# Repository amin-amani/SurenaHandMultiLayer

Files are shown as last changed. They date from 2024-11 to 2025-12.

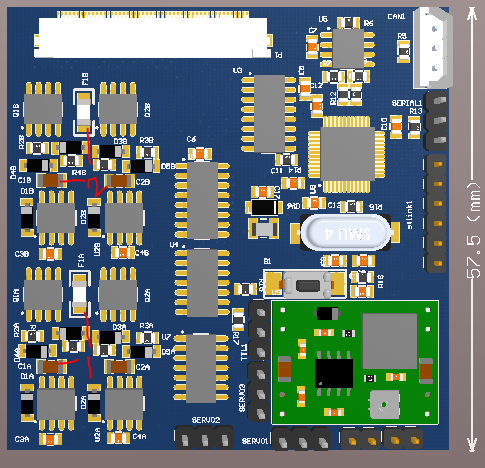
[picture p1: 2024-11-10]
Documentation/motor.PNG

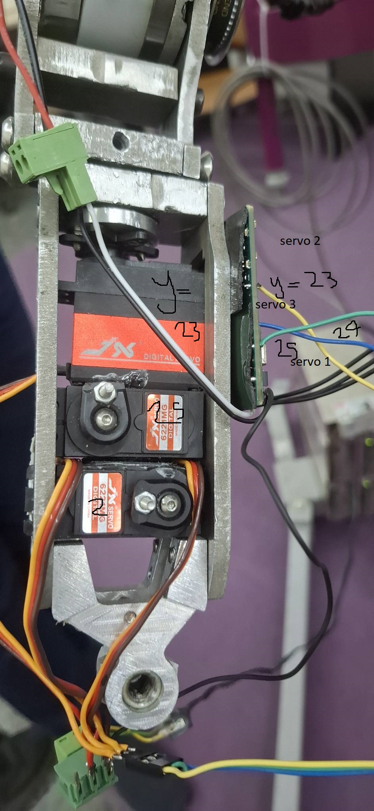
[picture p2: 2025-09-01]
Documentation/servo-connection.jpg

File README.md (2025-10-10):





# SurenaHandMultiLayer

This project provides firmware to control a robotic hand with multiple fingers. It integrates motor control, sensor feedback, and communication over CAN bus, enabling precise manipulation and customization for each finger.

## Features

6 Motor Control: Independently control each finger using dedicated motor drivers.

## Sensor Feedback:

BMP280 Sensors: Measure pressure/altitude data for feedback.

Potentiometers: Provide real-time position feedback of fingers.

CAN Bus Communication: Accepts commands via CAN for integration with other controllers or systems.

Finger Customization: Assign and configure individual PID values for each finger.

Extra Servo Output: Additional output for auxiliary mechanisms or accessories.

## Hardware Requirements

Robotic hand with 6 actuated fingers

BMP280 sensors for pressure/position measurement

Potentiometers on each finger for position feedback

Microcontroller with CAN interface

Motor drivers compatible with chosen motors

Optional servo for additional output

## Build Instructions:

use STM32CubeIDE

Flash Firmware:

st-flash write <firmware.bin> 0x8000000

## Usage

Send commands via CAN to control finger positions.

Monitor sensor feedback (BMP280 and potentiometers) for precise control.

Configure each finger using the IDE controller parameters.

Utilize the extra servo output for additional functionality.

## Contributing

Contributions are welcome! Please open an issue or submit a pull request with improvements, bug fixes, or new features.

## License

GPL

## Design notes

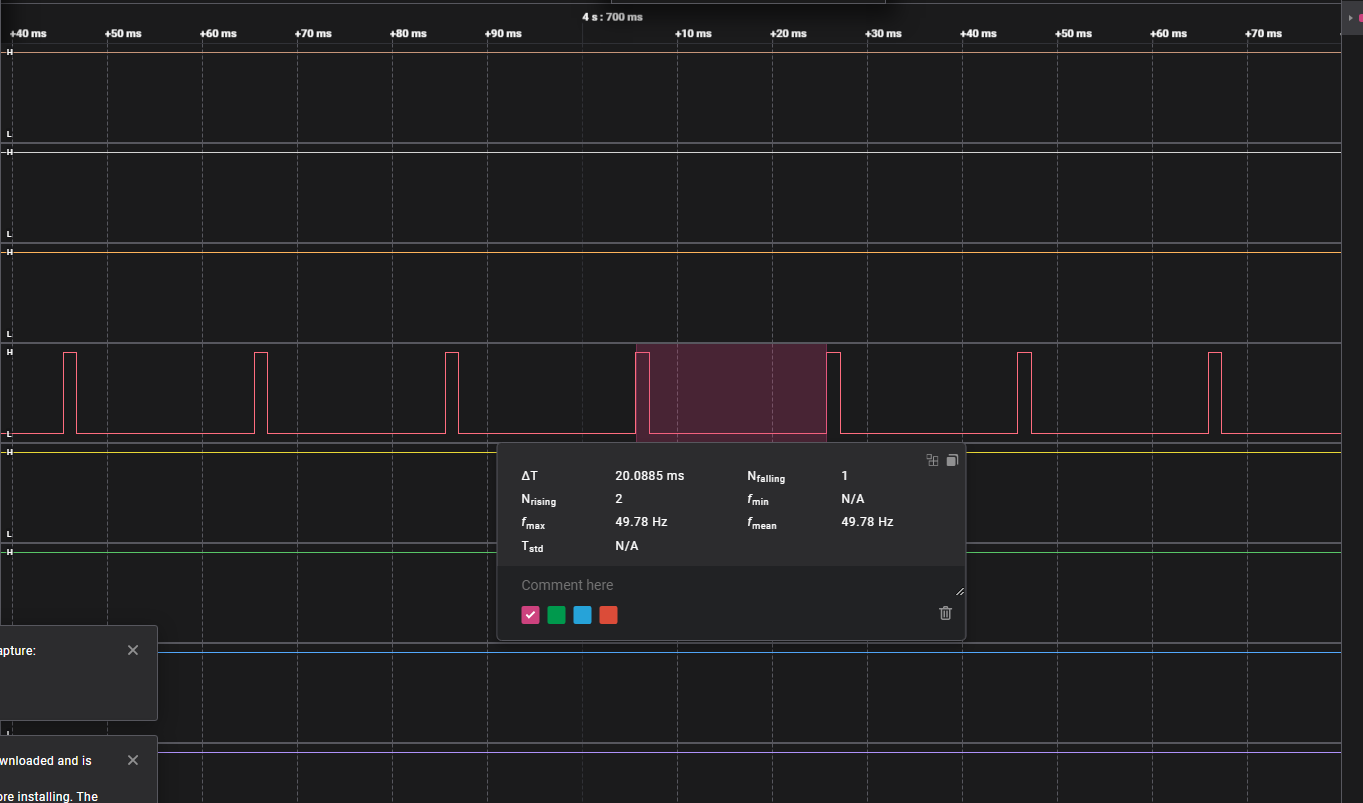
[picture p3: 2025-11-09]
Documentation/pwm timing.PNG

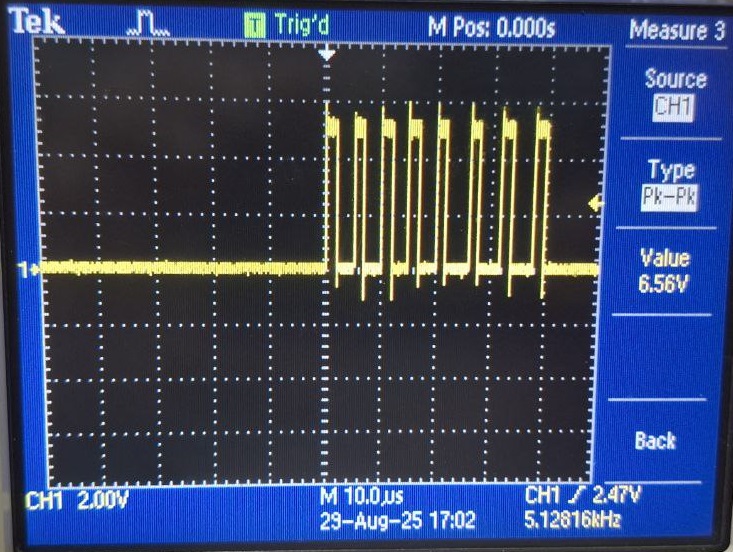
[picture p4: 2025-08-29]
Documentation/bmp280_clock1.jpg

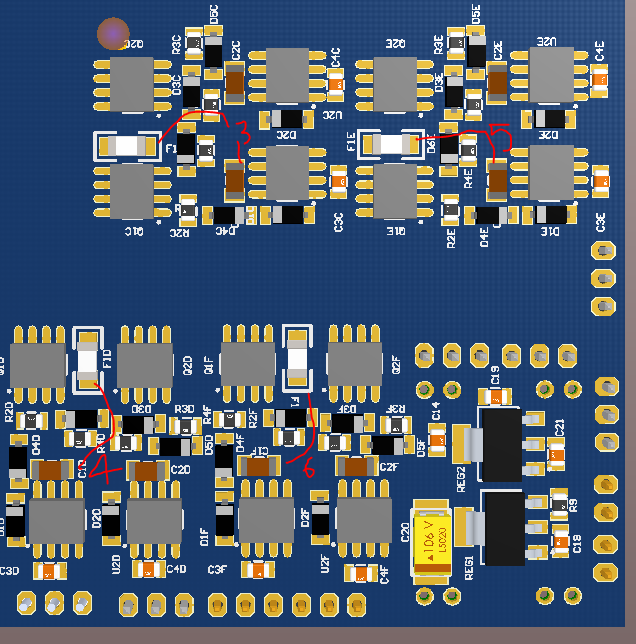
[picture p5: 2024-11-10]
Documentation/motor-back.PNG

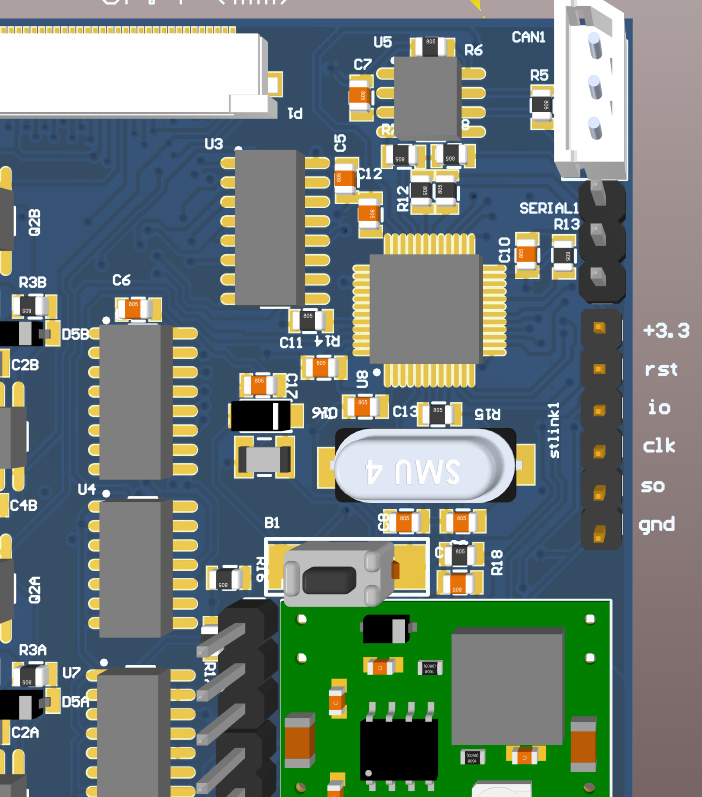
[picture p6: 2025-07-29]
Documentation/PROGRAMMER.PNG

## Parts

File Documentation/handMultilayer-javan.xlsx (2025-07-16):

Comment | Description | Designator | Footprint | LibRef | Quantity
button |  | B1 | SMD PUSH BUTTON | SMD_PUSH_BUTTON | 1 | https://www.javanelec.com/shops/productdetail/3080/tsuy-3sl
470NF | 3.2 mm × 1.6 mm | C1A, C1B, C1C, C1D, C1E, C1F, C2A, C2B, C2C, C2D, C2E, C2F | MY_CAP_SMD_1206 | CAP SMD_1206 | 12 | https://www.javanelec.com/shops/productdetail/7629
100NF | 2.0 mm × 1.25 mm | C3A, C3B, C3C, C3D, C3E, C3F, C4A, C4B, C4C, C4D, C4E, C4F, C7, C14 | MY_CAP_SMD_0805 | CAP SMD_0805 | 14 | https://www.javanelec.com/shops/productdetail/4185
100n |  | C5, C6, C10, C11, C12, C13, C17, C18, C19, C21 | MY_CAP_SMD_0805 | CAP SMD | 10
20p |  | C8, C9 | MY_CAP_SMD_0805 | CAP SMD | 2
22Pf |  | C15 | MY_CAP_SMD_0805 | CAP SMD | 1
10uf |  | C16 | MY_cap_smd10uf | cap_smd_10u | 1 | https://www.javanelec.com/shops/productdetail/7595
Cap | 6X3.2MM | C20 | MY_CAP_SMD-C | CAP_TANTAL_C | 1
pin_gerd | 3pin | CAN1 | MY_PINGERD3 | pin_gerd | 1
1N4148 |  | D1A, D1B, D1C, D1D, D1E, D1F, D2A, D2B, D2C, D2D, D2E, D2F, D3A, D3B, D3C, D3D, D3E, D3F, D4A, D4B, D4C, D4D, D4E, D4F, D5A, D5B, D5C, D5D, D5E, D5F, D6A, D6B, D6C, D6D, D6E, D6F | MY_DIOD1N5822_SMD | 1N5822-smd-5*2mm | 36 | https://www.javanelec.com/shops/productdetail/13747
FUSE 1206 |  | F1A, F1B, F1C, F1D, F1E, F1F | FUSE1206 | FUSE 1206 | 6 | https://www.javanelec.com/shops/productdetail/5914
100UH |  | L1 | MY_SMD_INDUCTOR | INDUCTOR SMD | 1
FPC |  | P1 | FPC-50-POS-0.5-MM | FPC-50-POS-0.5-MM | 1
Header 2 | Header, 2-Pin | pw, servopw | My_1X02 | Header 2 | 2
IRF7303 | HEXFET Power MOSFET | Q1A, Q1B, Q1C, Q1D, Q1E, Q1F, Q2A, Q2B, Q2C, Q2D, Q2E, Q2F | SO-8_N | IRF7303 | 12 | https://www.javanelec.com/shops/productdetail/7873
10 |  | R1A, R1B, R1C, R1D, R1E, R1F, R2A, R2B, R2C, R2D, R2E, R2F, R3A, R3B, R3C, R3D, R3E, R3F, R4A, R4B, R4C, R4D, R4E, R4F | MY_RES_SMD_0805 | RES SMD 0805 | 24 | https://www.javanelec.com/shops/productdetail/3973
120 |  | R5, R6 | MY_RES_SMD_0805 | RES SMD 0805 | 2 | https://www.javanelec.com/shops/productdetail/3982
1.8k |  | R7, R17 | MY_RES_SMD_0805 | RES SMD 0805 | 2 | https://www.javanelec.com/shops/productdetail/3972
3.3K |  | R8, R16 | MY_RES_SMD_0805 | RES SMD 0805 | 2 | https://www.javanelec.com/shops/productdetail/4020
0 |  | R9 | MY_RES_SMD_0805 | RES SMD | 1
100 |  | R11, R12 | MY_RES_SMD_0805 | RES SMD 0805 | 2 | https://www.javanelec.com/shops/productdetail/3974
100k |  | R13 | MY_RES_SMD_0805 | RES SMD | 1
10k |  | R14, R18 | MY_RES_SMD_0805 | RES SMD | 2
220 |  | R15 | MY_RES_SMD_0805 | RES SMD | 1
LD1117 3.3 |  | REG1 | MY_LD1117-3.3 | LD1117 3.3 | 1 | https://www.javanelec.com/shops/productdetail/8350/ams1117-3.3
LD1117 5 |  | REG2 | MY_LD1117-3.3 | LD1117 3.3 | 1 | https://www.javanelec.com/shops/productdetail/21714/ams1117-5.0
Header 3 | Header, 3-Pin | SERIAL1, SERVO1, SERVO2, SERVO3, TTL1 | My_1X03 | Header 3 | 6 | https://www.javanelec.com/shops/productdetail/1670
IR2104S | High and Low Side Driver | U1A, U1B, U1C, U1D, U1E, U1F, U2A, U2B, U2C, U2D, U2E, U2F | SO-8_N | IR2104S | 12 | https://www.javanelec.com/shops/productdetail/7873
M74HC238M1R | 3-to-8 Line Decoder | U3 | SO16_N | M74HC238M1R | 1 | https://www.javanelec.com/shops/productdetail/8176
HCF4001BM1 | Quad 2-Input NOR Gate | U4 | SO14_N | HCF4001BM1 | 1
MCP2551-I/SN | High-Speed CAN Transceiver, 8-Pin SOIC, Industrial Temperature | U5 | SOIC-SN8_N | MCP2551-I/SN | 1 | https://www.javanelec.com/shops/productdetail/19617
MC74HC138AD | 1-of-8 Decoder/Demultiplexer | U6 | 751B-03_N | MC74HC138AD | 1 | https://www.javanelec.com/shops/productdetail/8163
MC74HC125AD | Quad 3-State Non-Inverting Buffer | U7 | 751A-02_N | MC74HC125AD | 1 | https://www.javanelec.com/shops/productdetail/8159
STM32F103C8T6 | STM32 ARM-based 32-bit MCU with 64 Kbytes Flash, 48-pin LQFP, Industrial Temperature | U8 | LQFP48_N | STM32F103C8T6 | 1 | https://www.javanelec.com/shops/productdetail/8649
MP1584 | SWITCHING REGULATOR MODULE | U9 | mp1584 | MP1584 | 1 | https://www.javanelec.com/shops/productdetail/35031/mp1584-module
8mhz | Crystal | Y1 | My_Crystal - SMD | CRYSTAL | 1

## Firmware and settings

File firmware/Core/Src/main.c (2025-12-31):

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
/* Includes ------------------------------------------------------------------*/
#include "main.h"

/* USER CODE BEGIN Includes */
#include "logic.h"
#include "delay.h"
#include <stdbool.h>
#include "bmp280.h"
/* USER CODE END Includes */

/* USER CODE BEGIN PD */
#define FILTER_MEM_COUNT (5)
#if (FILTER_MEM_COUNT % 2) == 0
#error "FILTER_MEM_COUNT must be odd for median filter"
#endif
/* USER CODE END PD */

ADC_HandleTypeDef hadc1;
DMA_HandleTypeDef hdma_adc1;

CAN_HandleTypeDef hcan;

SPI_HandleTypeDef hspi1;

TIM_HandleTypeDef htim1;
TIM_HandleTypeDef htim2;
TIM_HandleTypeDef htim3;
TIM_HandleTypeDef htim4;

/* USER CODE BEGIN PV */
uint16_t ADCResult[5];
int count=0;
int i=0;
int pwm1=1000,pwm2=1000;
/* USER CODE END PV */

void SystemClock_Config(void);
static void MX_GPIO_Init(void);
static void MX_DMA_Init(void);
static void MX_ADC1_Init(void);
static void MX_CAN_Init(void);
static void MX_TIM4_Init(void);
static void MX_SPI1_Init(void);
static void MX_TIM3_Init(void);
static void MX_TIM1_Init(void);
static void MX_TIM2_Init(void);
/* USER CODE BEGIN PFP */
void hw_read_adc(uint16_t*value);
int  hw_can_send(uint32_t id,uint8_t *data);
void hw_set_direction(bool dir);
void hw_set_servo_position(uint8_t  *position);
//value is between 0 to 5
void hw_select_driver_motor(uint8_t value);
//minus means clockwise
void hw_set_motor_speed(uint8_t motor,int32_t speed );

void SelectSensor(int8_t index);
void SpiWrite(uint8_t index,uint8_t *data,int len);
void hw_toggle_test_pin();
void SPIReadWrite(uint8_t index,uint8_t *txBuffer,uint8_t txLen,uint8_t *rxBuffer,uint8_t rxLen);
void hw_set_servo_position(uint8_t  *position);
BMP280_CALLBACK_STRUCT_TYPE bmp_sensor=
{
	SPIReadWrite,
	SpiWrite

};


/* USER CODE END PFP */

/* USER CODE BEGIN 0 */
void SysTick_Initialize(uint32_t ticks)
{
    SysTick->CTRL = 0;  // Stop SysTick
    SysTick->LOAD = ticks - 1;
    SysTick->VAL  = 0;

    NVIC_SetPriority(SysTick_IRQn, 15);

    SysTick->CTRL = SysTick_CTRL_CLKSOURCE_Msk |
                    SysTick_CTRL_TICKINT_Msk   |
                    SysTick_CTRL_ENABLE_Msk;
}

void systick_interrupt_handler()
{
	//every 1.67ms
	run_pid_for_all_fingers();
}

void HAL_TIM_PeriodElapsedCallback(TIM_HandleTypeDef *htim1)
{
	static int step1 = 0;
	static int step2 = 0;
	if(htim1->Instance == TIM1)
	{

		if(step1 == 0)
		{

			GPIOB->ODR |=1<<7;
			TIM1->ARR = pwm1;
			step1 = 1;
		}
		else if(step1 == 1)
		{

			GPIOB->ODR &=~(1<<7);
			TIM1->ARR = 19500-pwm1;
			step1 = 0;
		}

	}
	if(htim1->Instance == TIM2)
	{
		if(step2 == 0)
		{

			GPIOB->ODR |=(1<<6);
			TIM2->ARR = pwm2;
			step2 = 1;
		}
		else if(step2 == 1)
		{

			GPIOB->ODR&=~(1<<6);
			TIM2->ARR = 19500-pwm2;
			step2 = 0;
		}

	}

}
void HAL_ADC_ConvHalfCpltCallback(ADC_HandleTypeDef* hadc)
{
	__NOP();
}
void HAL_ADC_ConvCpltCallback(ADC_HandleTypeDef* hadc)
{
	count++;
//	__NOP();
	//  printf("adc=%d %d %d %d %d %d\n",ADCResult[0],ADCResult[1],ADCResult[2],ADCResult[3],ADCResult[4],ADCResult[5]);

}
void HAL_CAN_RxFifo0MsgPendingCallback(CAN_HandleTypeDef *hcan)
{
	uint8_t               RxData[8];
	CAN_RxHeaderTypeDef   RxHeader;
	HAL_CAN_GetRxMessage(hcan, CAN_RX_FIFO0, &RxHeader, RxData);
	can_data_received(RxHeader.StdId,RxData);


}
/* USER CODE END 0 */

/**
  * @brief  The application entry point.
  * @retval int
  */
int main(void)
{

  /* MCU Configuration--------------------------------------------------------*/

  /* Reset of all peripherals, Initializes the Flash interface and the Systick. */
  HAL_Init();

  /* Configure the system clock */
  SystemClock_Config();

  /* Initialize all configured peripherals */
  MX_GPIO_Init();
  MX_DMA_Init();
  MX_ADC1_Init();
  MX_CAN_Init();
  MX_TIM4_Init();
  MX_SPI1_Init();
  MX_TIM3_Init();
  MX_TIM1_Init();
  MX_TIM2_Init();
  /* USER CODE BEGIN 2 */
	  printf("start app\n");
     hw_select_driver_motor(7);

  if (HAL_CAN_Start(&hcan) != HAL_OK)
     {
       /* Start Error */
 	  printf("can start error\n");
     }
   else{
 	  printf("can start ok!!!!!\n");
   }

#ifdef RIGHT_HAND
	  printf("right hand\n");
#else
	  printf("left hand\n");
#endif

  HAL_CAN_ActivateNotification(&hcan, CAN_IT_RX_FIFO0_MSG_PENDING);
  HAL_ADC_Start_DMA(&hadc1, (uint32_t*)ADCResult, 6);
  HAL_TIM_PWM_Start(&htim4, TIM_CHANNEL_3);
  HAL_TIM_PWM_Start(&htim4, TIM_CHANNEL_2);
  HAL_TIM_PWM_Start(&htim4, TIM_CHANNEL_1);
  HAL_TIM_PWM_Start(&htim3, TIM_CHANNEL_2);
  /* USER CODE END 2 */

  /* Infinite loop */
  /* USER CODE BEGIN WHILE */
  register_delay(HAL_Delay);
  bmp280_register_callbacks(&bmp_sensor);


  logic_register_adc(hw_read_adc);
  logic_register_can_send(hw_can_send);
  logic_register_set_motor_speed(hw_set_motor_speed);
  logic_register_set_servo_position(hw_set_servo_position);
  logic_register_read_pressure(bmp280_read_pressure);
  logic_register_read_temperature(bmp280_read_temperature);
  logic_register_sensor_init(bmp280_init);
  logic_register_hw_pin(hw_toggle_test_pin);
  logic_init();
  hw_set_motor_speed(7,0);

  HAL_NVIC_SetPriority(TIM1_UP_IRQn, 0, 0);
  HAL_NVIC_EnableIRQ(TIM1_UP_IRQn);
  HAL_NVIC_EnableIRQ(TIM2_IRQn);
  HAL_TIM_Base_Start_IT(&htim1);
  HAL_TIM_Base_Start_IT(&htim2);
  SysTick_Initialize(60000);
  while (1)
  {

	  logic_loop();
//	  hw_toggle_test_pin();
    /* USER CODE END WHILE */

    /* USER CODE BEGIN 3 */
  }
  /* USER CODE END 3 */
}

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
/* USER CODE BEGIN 4 */

int _write(int file, char *ptr, int len)
{
	/* Implement your write code here, this is used by puts and printf for example */
	int i=0;
	for(i=0 ; i<len ; i++)
		ITM_SendChar((*ptr++));
	return len;
}

static void sort_uint16(uint16_t *arr, uint8_t size)
{
    for (uint8_t i = 1; i < size; i++)
    {
        uint16_t key = arr[i];
        int8_t j = i - 1;

        while (j >= 0 && arr[j] > key)
        {
            arr[j + 1] = arr[j];
            j--;
        }
        arr[j + 1] = key;
    }
}

void filter_adc_values(uint16_t *filtered_value,
                       uint16_t adc_raw_value[6][FILTER_MEM_COUNT])
{
    uint16_t temp[FILTER_MEM_COUNT];

    for (int ch = 0; ch < 6; ch++)
    {

        for (int i = 0; i < FILTER_MEM_COUNT; i++)
        {
            temp[i] = adc_raw_value[ch][i];
        }


        sort_uint16(temp, FILTER_MEM_COUNT);


        filtered_value[ch] = temp[FILTER_MEM_COUNT / 2];
    }
}

void hw_read_adc(uint16_t *value)
{
//    static uint16_t filter_memory[6][FILTER_MEM_COUNT];
//    static uint16_t adc_filtered[6] = {2000,2000,2000,2000,2000,2000};
//    static int index = 0;
//
//    for (int channel = 0; channel < 6; channel++)
//    {
//        filter_memory[channel][index] = ADCResult[channel];
//    }
//
//    index++;
//
//    if (index == FILTER_MEM_COUNT)
//    {
//        index = 0;
//        filter_adc_values(adc_filtered, filter_memory);
//    }

    memcpy(value, ADCResult, 6 * sizeof(uint16_t));
}

int hw_can_send(uint32_t id,uint8_t *data)
{
	CAN_TxHeaderTypeDef   TxHeader;
	uint32_t              TxMailbox;
	  /*##-4- Start the Transmission process #####################################*/
	  TxHeader.StdId =id;
	  TxHeader.RTR = CAN_RTR_DATA;
	  TxHeader.IDE = CAN_ID_STD;
	  TxHeader.DLC = 8;
	  TxHeader.TransmitGlobalTime = DISABLE;

	  /* Request transmission */
	  if(HAL_CAN_AddTxMessage(&hcan, &TxHeader, data, &TxMailbox) != HAL_OK)
	  {
	    /* Transmission request Error */
		  printf("Transmission request Error\n");
		 return -1;
	  }
	  return 0;
}


void hw_set_direction(bool dir)
{
	GPIOB->ODR &=~(1<<12);
	if(dir)GPIOB->ODR |=(1<<12);
}
//value is between 0 to 5
void hw_select_driver_motor(uint8_t value)
{
	value&=0x07;
	GPIOB->ODR &=~(0x07<<13);
	GPIOB->ODR |=(value<<13);
}

void hw_set_servo_position(uint8_t  *position)
{
//	TIM4->CCR1 = 50+((position[0]>190)?190:position[0]);
//	TIM4->CCR2 = 50+((position[1]>190)?190:position[1]);
	TIM3->CCR2 = 50+((position[2]>190)?190:position[2]);
	pwm1 = 488+((position[0]>190)?190:(position[0]<20)?20:position[0])*10;
	pwm2 = 488+((position[1]>190)?190:(position[1]<20)?20:position[1])*10;

}
//minus means clockwise
void hw_set_motor_speed(uint8_t motor,int32_t speed )
{


	if(speed<0) {
		hw_set_direction(0);
		speed*=-1;
	}
	else{
		hw_set_direction(1);

	}
	speed=1900-speed;
	if(speed>1900)speed=1900;
	if(speed<2)speed =2;

	hw_select_driver_motor(motor);

	 TIM4->CCR3=speed;



}
void SelectSensor(int8_t index)
{

        GPIOB->ODR &= ~ ((0x07)<<9);
        GPIOB->ODR |= ((0x07 & index)<<9);
}


void SpiWrite(uint8_t index,uint8_t *data,int len)
{
	int offset=-1;
	//if(index==1)offset=1;
	SelectSensor(index+offset);
//	GPIOB->ODR&=~(1<<9);
	HAL_SPI_Transmit(&hspi1, data, len, 1000); //CONFIG
//	GPIOB->ODR|=1<<9;
	SelectSensor(index);
}

void hw_toggle_test_pin()
{
 GPIOA->ODR ^= 1<<9;
}

void SPIReadWrite(uint8_t index,uint8_t *txBuffer,uint8_t txLen,uint8_t *rxBuffer,uint8_t rxLen)
{
	HAL_Delay(5);
	int offset=-1;
	//if(index==1)offset=1;
	SelectSensor(index+offset);
	HAL_Delay(1);
//	GPIOB->ODR&=~(1<<9);
	HAL_SPI_Transmit(&hspi1, txBuffer, txLen, 10);
	HAL_SPI_Receive(&hspi1, rxBuffer, rxLen, 200);
	SelectSensor(index);
//	GPIOB->ODR|=1<<9;
	HAL_Delay(1);

}
/* USER CODE END 4 */
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


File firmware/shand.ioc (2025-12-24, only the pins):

Mcu.UserName=STM32F103C8Tx
PA0-WKUP.Signal=ADCx_IN0
PA1.Signal=ADCx_IN1
PA11.Signal=CAN_RX
PA12.Signal=CAN_TX
PA13.Signal=SYS_JTMS-SWDIO
PA14.Signal=SYS_JTCK-SWCLK
PA2.Signal=ADCx_IN2
PA3.Signal=ADCx_IN3
PA4.Signal=ADCx_IN4
PA5.Signal=SPI1_SCK
PA6.Signal=SPI1_MISO
PA7.Signal=SPI1_MOSI
PA9.Signal=GPIO_Output
PB0.Signal=ADCx_IN8
PB10.GPIO_Label=SPI_SEL1
PB10.Signal=GPIO_Output
PB11.GPIO_Label=SPI_SEL2
PB11.Signal=GPIO_Output
PB12.GPIO_Label=DIRVER_DIRECTION
PB12.Signal=GPIO_Output
PB13.GPIO_Label=DRIVER_SELECT0
PB13.Signal=GPIO_Output
PB14.GPIO_Label=DRIVER_SELECT1
PB14.Signal=GPIO_Output
PB15.GPIO_Label=DRIVER_SELECT2
PB15.Signal=GPIO_Output
PB3.Signal=SYS_JTDO-TRACESWO
PB5.Signal=S_TIM3_CH2
PB6.Signal=GPIO_Output
PB7.Signal=GPIO_Output
PB8.Signal=S_TIM4_CH3
PB9.GPIO_Label=SPI_SEL0
PB9.Signal=GPIO_Output
PD0-OSC_IN.Signal=RCC_OSC_IN
PD1-OSC_OUT.Signal=RCC_OSC_OUT

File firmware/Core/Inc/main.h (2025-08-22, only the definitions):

#define SPI_SEL1_Pin GPIO_PIN_10
#define SPI_SEL1_GPIO_Port GPIOB
#define SPI_SEL2_Pin GPIO_PIN_11
#define SPI_SEL2_GPIO_Port GPIOB
#define DIRVER_DIRECTION_Pin GPIO_PIN_12
#define DIRVER_DIRECTION_GPIO_Port GPIOB
#define DRIVER_SELECT0_Pin GPIO_PIN_13
#define DRIVER_SELECT0_GPIO_Port GPIOB
#define DRIVER_SELECT1_Pin GPIO_PIN_14
#define DRIVER_SELECT1_GPIO_Port GPIOB
#define DRIVER_SELECT2_Pin GPIO_PIN_15
#define DRIVER_SELECT2_GPIO_Port GPIOB
#define SPI_SEL0_Pin GPIO_PIN_9
#define SPI_SEL0_GPIO_Port GPIOB

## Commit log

2024-11-07 feat: created schematic and pcb files
    [Bridge.SchDoc, Driver.SchDoc, HAND-MULTILAYER.PcbLib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]
2024-11-07 feat: implement printf over stlink
2024-11-08 feat: can read and write ok works with internal occilator in 32mh
    [hand_multillayer.cfg]
2024-11-10 feat: follow perfs file to check if it is impotant to track
2024-11-10 feat: pwm output generated and can works fine
2024-11-10 feat: all drivers tested with real motor I should test pwm freq
2024-12-03 feat: add spi to project
2024-12-03 feat: sensor works but after reset
    [main.c]
2024-12-31 feat: enable adc on port a
2024-12-31 feat: read 5 adc on port A steel need verification
2024-12-31 feat: add channel pb0 as adc channell 8
2024-12-31 feat: read all adc worked fine but I dont know why adc channel changed
2025-07-16 feat: add bom to project
    [handMultilayer-javan.xlsx]
2025-07-25 feat resolve wrong enable pin connection
    [main.SchDoc]
2025-07-29 feat: create motor function to set speed
2025-08-08 feat: redesign with cube ide 1.17.0
    [hand_multillayer.cfg]
2025-08-09 feat: create standard structure
    [Bridge.SchDoc, Driver.SchDoc, HAND-MULTILAYER.SchLib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]
2025-08-15 feat: generate gerber and nc driels
    [HAND_MULTILAYER.GBL, HAND_MULTILAYER.GBO, HAND_MULTILAYER.GBP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]
2025-08-16 feat: test more fingers
2025-08-22 feat: read bmp sensor
2025-08-22 fix: resolve broken test
    [bmp280.c]
2025-08-24 fix: gen info switch problem
2025-08-27 disable motors at first
2025-08-29 feat: change spi frequence to 281.25 kb/s now sensor works
2025-08-29 feat: check and configure servo signals
2025-08-29 feat: define min and max for middle and ring fingers
2025-09-01 feat: register hw servo write value in logic
2025-09-01 feat: add command to read sensor values
2025-09-01 doc: add servo connection image
2025-09-01 test: fix broken test
    [logic_test.c]
2025-09-10 feat: init servo position at startup
2025-09-17 feat: add init servo positions
2025-09-17 fix: remove code cause breaking test
    [logic_test.c]
2025-09-19 chore: rename doc folder
    [handMultilayer-javan.xlsx]
2025-09-19 feat: create interface for sensor functions
2025-09-24 fix: minor bugs fixed during tests
    [logic.c]
2025-09-24 fix: set_servo_goal_position must be customized for right and left hand boards individually
    [logic.c, main.c]
2025-10-02 feat: mix control logic loop with adc and pressure sensors
    - position values scale
    - pid values scale
    - TODO: pressure values scale to be fixed
    [logic.c, logic.h, logic_test.c]
2025-10-21 fix: change hand limits and offsets
    [logic.c, logic.h]
2025-10-28 fix: change hand limits for right hand
    [logic.h]
2025-10-28 fix: some pid emelemts must be negative
    [logic.c]
2025-11-09 feat: all fingers works with pid
2025-11-20 feat: change pwm frequency
2025-11-24 feat: use timer 1 and timer 2 to create servo pulses
2025-11-25 fix: set finger limits
    [logic.c, logic.h]
2025-11-25 fix: servo position works fine
    [main.c]
2025-11-26 feat: stop all motors when they reached
2025-11-27 feat: update sensor values
2025-11-27 feat: use round robin on sensor read
2025-11-30 fix: change servo order position
    [logic.c, logic.h, main.c]
2025-12-01 fix: right hand motor index
    [logic.c, logic.h]
2025-12-11 fix: use and or operator instead of xor to value gpio
    [logic.h, main.c]
2025-12-14 feat: sperate left and right finger position
2025-12-14 feat: stop fingers if poentiomerts are out of range
2025-12-24 feat: increase adc sample time
2025-12-29 feat: add format median filter
2026-01-01 fix: change adc offsets for right hand
    [logic.h]
2026-01-05 fix: change adc offsets for left hand
    [logic.h]
2026-01-07 feat: create offset for bmp sensors
2026-01-07 feat: add filter and add can id to c# app
2026-01-07 fix: set correct can id
    [logic.h]
2026-01-07 feat: add pressure limit for fingers

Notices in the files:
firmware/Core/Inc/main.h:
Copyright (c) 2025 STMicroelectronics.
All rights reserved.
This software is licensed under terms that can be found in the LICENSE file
